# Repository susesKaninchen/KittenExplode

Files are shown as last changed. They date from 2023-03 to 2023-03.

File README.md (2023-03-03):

# KittenExplode
Das Projekt besteht aus einem I2C MAster und einer Reihe von I2C Slaves.

Momentan ist es auf ESP32 ausgelegt, diese haben kein I2C stretching und deswegen verhalten sie sich anders als ESP32 C3 oder STM32 oder Arduinos. Der Slave code müste dann angepasst werden.

Der Slave kann das Status Byte (statusChar) anpassen um dem Master bescheid zu geben wie der aktuelle Status ist.
Der Master kann das EndByte (endByte) anpassen um den Slaves den Stand des Spiel mitzuteilen.
Der vom Master gesetzte Seed (seed) soll genutzt werden um die Slaves zu konfigurieren.

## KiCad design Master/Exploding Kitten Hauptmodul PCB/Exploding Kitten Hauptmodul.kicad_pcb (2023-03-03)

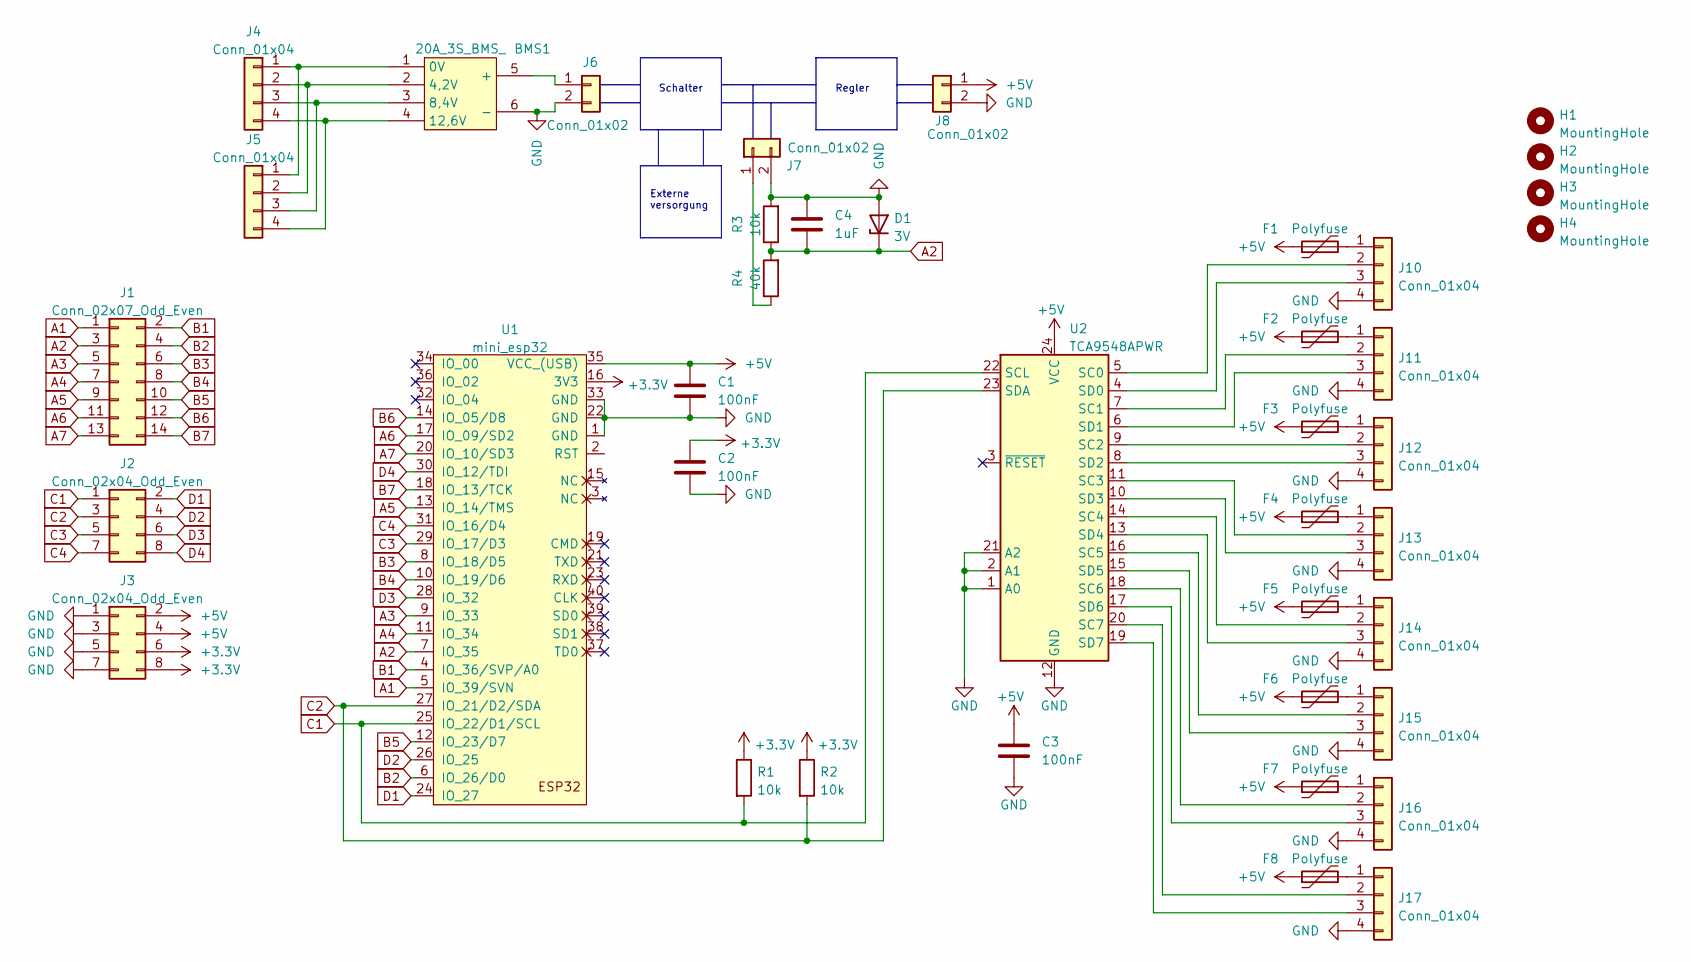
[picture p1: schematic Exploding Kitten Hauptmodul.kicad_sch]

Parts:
BMS1: 20A_3S_BMS_; 3S 20A BMS
C1, C2, C3: 100nF; C_0805_2012Metric
C4: 1uF; C_0805_2012Metric
D1: 3V; D_DO-41_SOD81_P7.62mm_Horizontal
F1, F2, F3, F4, F5, F6, F7, F8: Polyfuse; R_0805_2012Metric_Pad1.20x1.40mm_HandSolder
H1, H2, H3, H4: MountingHole; MountingHole_3.2mm_M3
J1: Conn_02x07_Odd_Even; PinHeader_2x07_P2.54mm_Vertical
J2, J3: Conn_02x04_Odd_Even; PinHeader_2x04_P2.54mm_Vertical
J4, J5, J10, J11, J12, J13, J14, J15, J16, J17: Conn_01x04; JST_EH_S4B-EH_1x04_P2.50mm_Horizontal
J6, J7, J8: Conn_01x02; TerminalBlock_bornier-2_P5.08mm
R1, R2, R3: 10k; R_0805_2012Metric
R4: 40k; R_0805_2012Metric
U1: mini_esp32; ESP32_mini
U2: TCA9548APWR; TSSOP-24_4.4x7.8mm_P0.65mm

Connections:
+3.3V: C2.1, J3.6, J3.8, R1.1, R2.1, U1.16 (3V3)
+5V: C1.1, C3.1, F1.1, F2.1, F3.1, F4.1, F5.1, F6.1, F7.1, F8.1, J3.2, J3.4, J8.1, U1.35 (VCC_(USB)), U2.24 (VCC)
A1: J1.1, U1.5 (IO_39/SVN)
A2: C4.2, D1.1 (K), J1.3, R3.1, R4.2, U1.7 (IO_35)
A3: J1.5, U1.9 (IO_33)
A4: J1.7, U1.11 (IO_34)
A5: J1.9, U1.13 (IO_14/TMS)
A6: J1.11, U1.17 (IO_09/SD2)
A7: J1.13, U1.20 (IO_10/SD3)
B1: J1.2, U1.4 (IO_36/SVP/A0)
B2: J1.4, U1.6 (IO_26/D0)
B3: J1.6, U1.8 (IO_18/D5)
B4: J1.8, U1.10 (IO_19/D6)
B5: J1.10, U1.12 (IO_23/D7)
B6: J1.12, U1.14 (IO_05/D8)
B7: J1.14, U1.18 (IO_13/TCK)
C1: J2.1, R1.2, U1.25 (IO_22/D1/SCL), U2.22 (SCL)
C2: J2.3, R2.2, U1.27 (IO_21/D2/SDA), U2.23 (SDA)
C3: J2.5, U1.29 (IO_17/D3)
C4: J2.7, U1.31 (IO_16/D4)
D1: J2.2, U1.24 (IO_27)
D2: J2.4, U1.26 (IO_25)
D3: J2.6, U1.28 (IO_32)
D4: J2.8, U1.30 (IO_12/TDI)
unnamed: BMS1.5 (+), J6.1
unnamed: F1.2, J10.1
unnamed: F2.2, J11.1
unnamed: F3.2, J12.1
unnamed: F4.2, J13.1
unnamed: F5.2, J14.1
unnamed: F6.2, J15.1
unnamed: F7.2, J16.1
unnamed: F8.2, J17.1
unnamed: BMS1.1 (0V), J4.1, J5.1
unnamed: BMS1.2 (4,2V), J4.2, J5.2
unnamed: BMS1.3 (8,4V), J4.3, J5.3
unnamed: BMS1.4 (12,6V), J4.4, J5.4
unnamed: J10.2, U2.5 (SC0)
unnamed: J10.3, U2.4 (SD0)
unnamed: J11.2, U2.7 (SC1)
unnamed: J11.3, U2.6 (SD1)
unnamed: J12.2, U2.9 (SC2)
unnamed: J12.3, U2.8 (SD2)
unnamed: J13.2, U2.11 (SC3)
unnamed: J13.3, U2.10 (SD3)
unnamed: J14.2, U2.14 (SC4)
unnamed: J14.3, U2.13 (SD4)
unnamed: J15.2, U2.16 (SC5)
unnamed: J15.3, U2.15 (SD5)
unnamed: J16.2, U2.18 (SC6)
unnamed: J16.3, U2.17 (SD6)
unnamed: J17.2, U2.20 (SC7)
unnamed: J17.3, U2.19 (SD7)
unnamed: J7.1, R4.1

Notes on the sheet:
Schalter
Externe versorgung
Regler

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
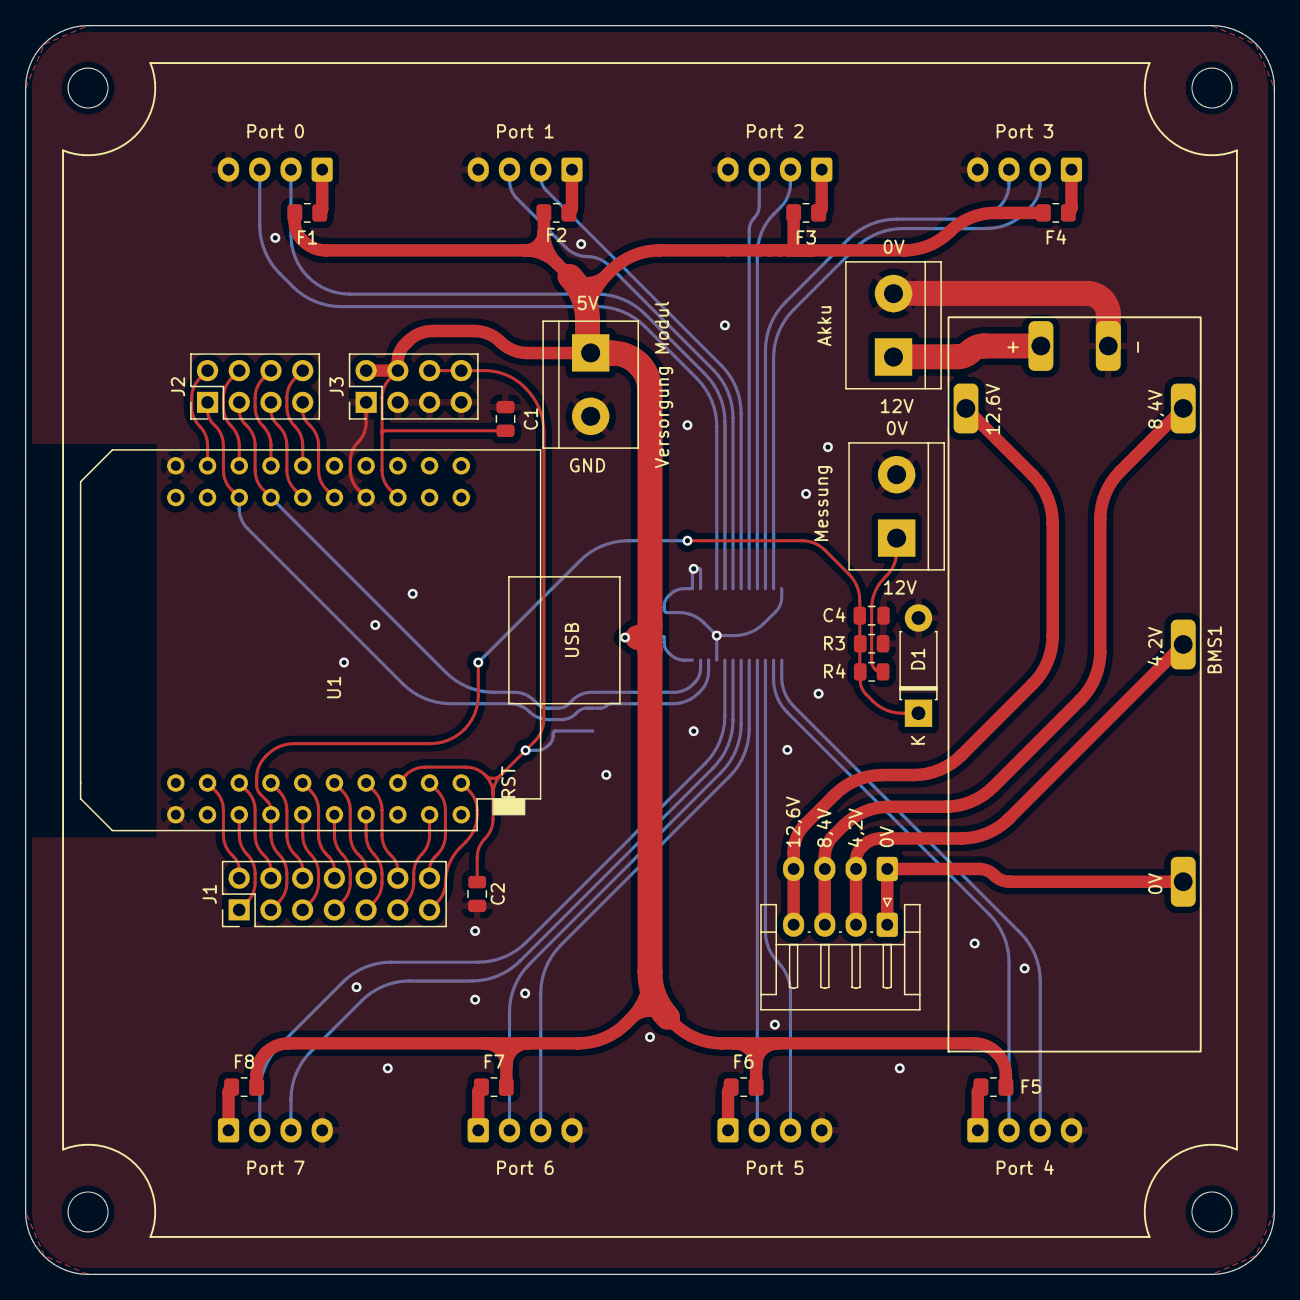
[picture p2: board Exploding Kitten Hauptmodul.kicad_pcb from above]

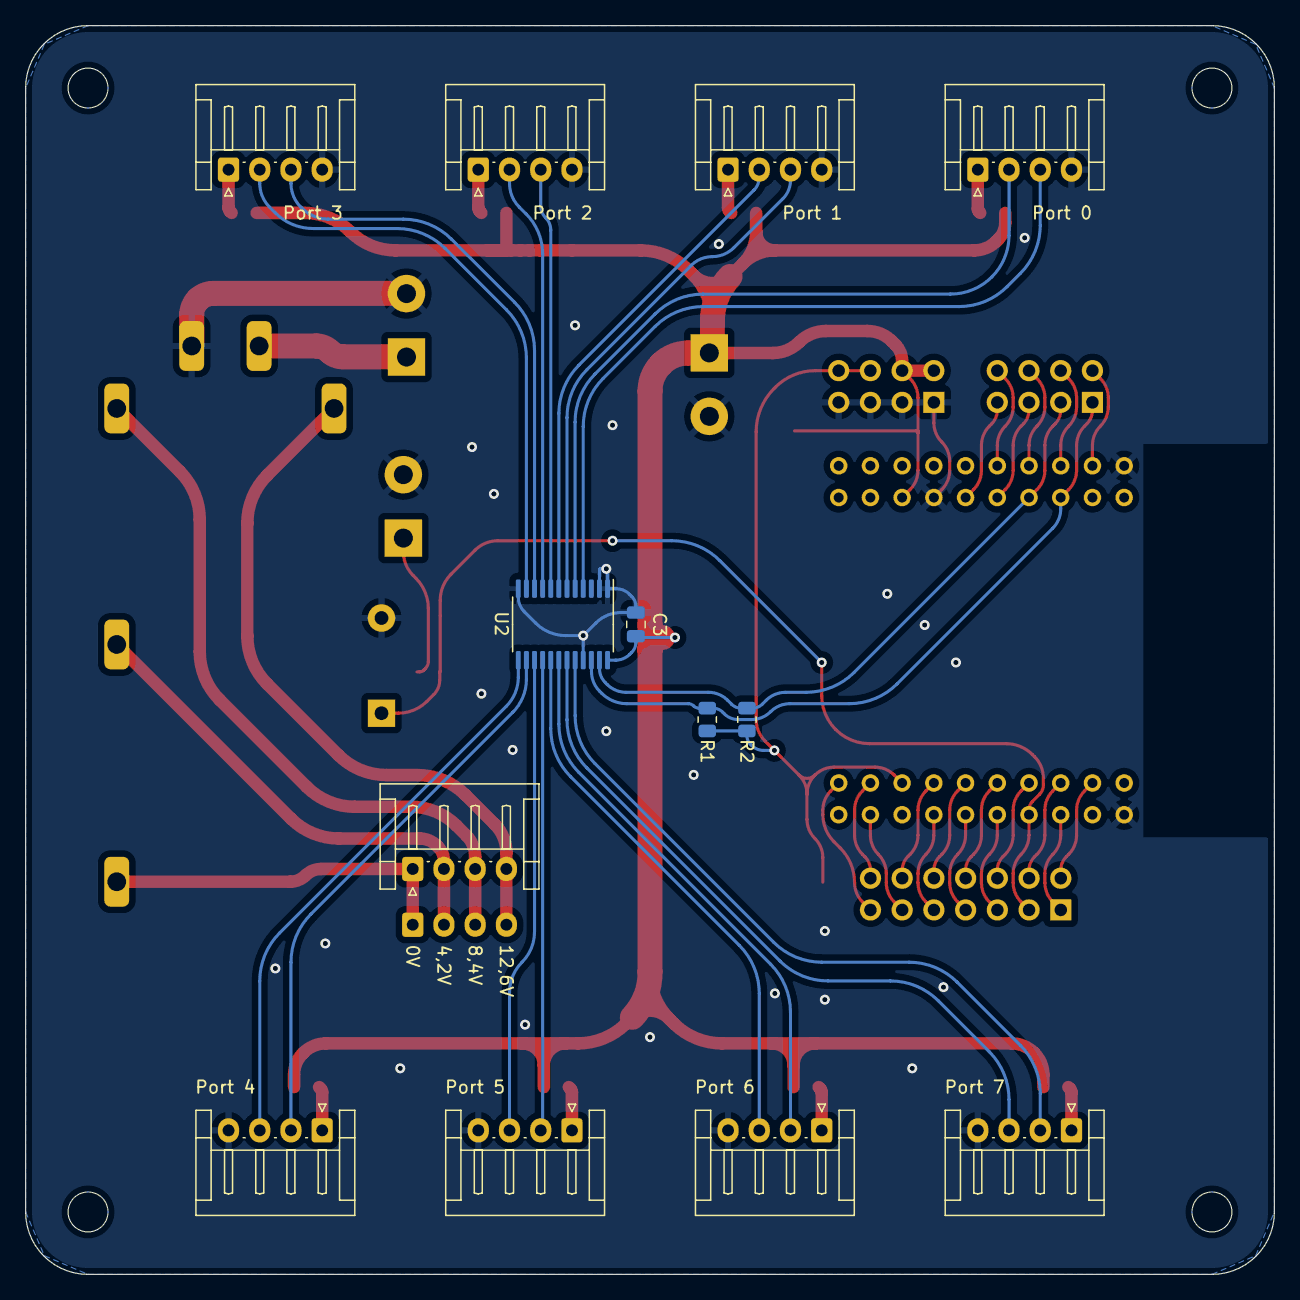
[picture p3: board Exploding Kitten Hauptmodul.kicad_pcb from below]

Board: 2 copper layers, 100.0 x 100.0 mm, 40 parts (13 on the bottom side), 55 nets.

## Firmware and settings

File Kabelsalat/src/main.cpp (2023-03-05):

#include <Arduino.h>
#include <WS2812FX.h>



// led pins
#define NUM_LEDS 10
#define DATA_PIN 25

// number of selected resistors
#define MIN_NUM 3
#define MAX_NUM 6

WS2812FX ws2812fx = WS2812FX(NUM_LEDS, DATA_PIN, NEO_GRBW + NEO_KHZ800);

// To-Do: get seed from master module
uint16_t seed = 54321;

// indexes of selected resistors
int selectedResistors[MAX_NUM];

// fills array with one value
void fillArray(int array[], int arraySize, int value) {
  for(int i = 0; i < arraySize; i++) {
    array[i] = value;
  } 
}

// returns true if integer is already in array
bool checkNumInArray(int array[], int arraySize, int checkNum) {
  for(int i = 0; i < arraySize; i++) {
    if(array[i] == checkNum) {
      return true;
    }
  }
  return false;
}

// returns pseudo-random number depending on the given seed
int roundedDigit(int num, int digit) {
  if(digit < 4) {
    return round((num / (10^(digit + 1))) % 10);
  }
  int a = round(num % 10);
  int b = round(num / 10^(digit - 3));
  return round((a*b) % 10);
}

// writes indexes of resistors to be lit up into selsectedResistors array
void selectResistors(uint16_t seed) {
  fillArray(selectedResistors, MAX_NUM, -1);
  // determine pseudorandom number of resistors between MIN_NUM and MAX_NUM values
  int numberOfResistors = round((seed % (MAX_NUM - MIN_NUM + 1))) + MIN_NUM;
  // determine unique, pseudorandom indexes
  for(int i = 0; i < numberOfResistors; i++) {
    int temp = roundedDigit(seed, i);
    while(checkNumInArray(selectedResistors, MAX_NUM, temp)) {
      temp++;
      if(temp == 10) {temp = 0;};
    }
    selectedResistors[i] = temp;
  }
}

// game logic
bool defuseOrBoom(int bridgedResistor, uint16_t seed) {
  return true;
}

// lights up selected resistors
void drawLeds(int array[]) {
  for(int i = 0; i < MAX_NUM; i++) {
    if(array[i] > -1) {
      ws2812fx.setColor(array[i], 0xffffffff);
    }
  }
}

// shuts off all leds
void ledsOff() {
  for(int i = 0; i < NUM_LEDS; i++) {
    ws2812fx.setColor(i, 0x00000000);
  }
}

void setup() {
  Serial.begin(115200);

  ws2812fx.init();
  ws2812fx.setBrightness(255);

  ws2812fx.setSegment(0, 0, 0, FX_MODE_STATIC, BLACK, 1000, false);
  ws2812fx.setSegment(1, 1, 1, FX_MODE_STATIC, BLACK, 1000, false);
  ws2812fx.setSegment(2, 2, 2, FX_MODE_STATIC, BLACK, 1000, false);
  ws2812fx.setSegment(3, 3, 3, FX_MODE_STATIC, BLACK, 1000, false);
  ws2812fx.setSegment(4, 4, 4, FX_MODE_STATIC, BLACK, 1000, false);
  ws2812fx.setSegment(5, 5, 5, FX_MODE_STATIC, BLACK, 1000, false);
  ws2812fx.setSegment(6, 6, 6, FX_MODE_STATIC, BLACK, 1000, false);
  ws2812fx.setSegment(7, 7, 7, FX_MODE_STATIC, BLACK, 1000, false);
  ws2812fx.setSegment(8, 8, 8, FX_MODE_STATIC, BLACK, 1000, false);
  ws2812fx.setSegment(9, 9, 9, FX_MODE_STATIC, BLACK, 1000, false);

  ws2812fx.start();
}

void loop() {
  selectResistors(seed);

  for(int i = 0; i < MAX_NUM; i++) {
    Serial.print(selectedResistors[i]);
    Serial.print(" ");
  }
  Serial.println();

  ledsOff();
  drawLeds(selectedResistors);

  ws2812fx.service();
  delay(1000);
  seed = random(10000, 60000);
  
}

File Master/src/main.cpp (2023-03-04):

#include "soc/rtc_wdt.h"

#include <Arduino.h>
#include "introducion.h"
#include <Wire.h>
#define LED_BUILTIN 2
#include "slaveCommunication.h"

#include <FS.h>
#include <LittleFS.h>
#define SPIFFS LittleFS
#include <WiFi.h>
#include <AsyncTCP.h>
#include <ESPAsyncWebServer.h>

#include <TM1637.h>
// Instantiation and pins configurations
// Pin 19 - > DIO
// Pin 18 - > CLK
TM1637 tm(18, 19);

#include <Adafruit_NeoPixel.h>
#define LED_PIN        26
#define NUMPIXELS 6
Adafruit_NeoPixel pixels(NUMPIXELS, LED_PIN, NEO_GRB + NEO_KHZ800);

AsyncWebServer server(80);

const char* ssid = "Kitten";
const char* password = "";

void notFound(AsyncWebServerRequest *request) {
    request->send(404, "text/plain", "Not found");
}

String processor(const String& var)
{
  if(var == "ANLEITUNG_1") {
    return getText(0);
  } else if (var == "ANLEITUNG_2") {
    return getText(1);
  } else if (var == "ANLEITUNG_3") {
    return getText(2);
  } else if (var == "ANLEITUNG_4") {
    return getText(3);
  } else if (var == "ANLEITUNG_5") {
    return getText(4);
  } else if (var == "ANLEITUNG_6") {
    return getText(5);
  } else if (var == "ANLEITUNG_7") {
    return getText(6);
  } else if (var == "ANLEITUNG_8") {
    return getText(7);
  } else if (var == "") {
    return "%";
  }
  return String("%" + var + "%");
}

int seedGobal = 0;
unsigned long timeGame = -1;
bool gameRunning = false;
byte gameStati = 0;
unsigned long startPoint = millis();
unsigned long lastWrite = millis();
int minUten = 0;
int sekunden = 0;
unsigned long ts = 0;

void setPixel(byte error) {
  for (int g = 0 ; g<3; g++) {
    if (error >= g+1){
      pixels.setPixelColor(g, pixels.Color(150, 0, 0));
    } else {
    pixels.setPixelColor(g, pixels.Color(0, 150, 0));
  }
  }
  pixels.show();
}

void setup() {
  Serial.begin(115200);
  while (!Serial);
  
  Wire.begin(); // join i2c bus (address optional for writer)

  IPAddress apIP(192,1,1,1);
  WiFi.softAP(ssid, password);
  WiFi.softAPConfig(apIP, apIP, IPAddress(255, 255, 255, 0));

  SPIFFS.begin();
  
  server.on("/init", HTTP_POST, [](AsyncWebServerRequest *request){
    if(request->hasParam("zahl")){
      AsyncWebParameter* p = request->getParam("zahl");
      seedGobal = atoi(p->value().c_str());
      timeGame = initSlaves(seedGobal);
      setEndSlaves(END_RUNNING);
      gameRunning = true;
      gameStati = 0;
      startPoint = millis();
      lastWrite = millis();
      minUten = 0;
      sekunden = 0;
      ts = 0;
    }
      request->redirect("/anleitung.html");
  });
  server.serveStatic("/img/", SPIFFS, "/img/");
  server.serveStatic("/", SPIFFS, "/").setTemplateProcessor(processor);
  
  server.onNotFound(notFound);
  server.begin();
  
  tm.begin();
  tm.setBrightness(4);
  tm.display(1111)->blink(1000);
  pixels.begin();
  pixels.clear();
  Serial.println("Master getartet");
}

void loop() {
  tm.display("IDLE")->scrollLeft(500);
  while (gameRunning) {
    //tell the wdt we are still alive
    rtc_wdt_feed();
    tm.clearScreen();
    ts = (int)(startPoint + timeGame * 1000 - millis())/1000;
    sekunden = (ts)%60;
    minUten = ts/60;
    tm.display((float) minUten + (sekunden/100));
    gameStati = getStatusSlaves();
    if (millis() > lastWrite + 2000) {
      setPixel(gameStati%25);
      Serial.print("Status\nFehler: ");
      Serial.println(gameStati%25);
      Serial.print("Seiten Geschafft: ");
      Serial.println((int) gameStati/25);
      Serial.print("Rest Zeit: ");
      Serial.println(startPoint + timeGame * 1000 - millis());// wenn -, dann sehr hoche zahl
      lastWrite = millis();
    }
    if (gameStati >= 200) {
      setPixel(0);
      setEndSlaves(END_WIN);
      Serial.println("Gewonnen");
      gameRunning = false;
    }else if (gameStati%25 >= 3) {
      setPixel(3);
      setEndSlaves(END_LOST);
      Serial.println("Verloren zu viele Fehler");
      gameRunning = false;
    } else if (millis() > startPoint + timeGame * 1000) {
      setPixel(3);
      setEndSlaves(END_LOST);
      Serial.println("Verloren Zeit ist um");
      gameRunning = false;
    }
    delay(1000);
  }
  delay(10000);
}

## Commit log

2023-03-03 Master PCB
    [Exploding Kitten Hauptmodul.kicad_pcb, Exploding Kitten Hauptmodul.kicad_sch]
2023-03-03 Segment und NeoPixel
2023-03-04 fix neopixel pin
2023-03-04 fix slave i2c connection as client
